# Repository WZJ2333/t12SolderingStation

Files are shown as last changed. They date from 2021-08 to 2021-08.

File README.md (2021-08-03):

# T12焊台

### 参考网址

原作者easyEda：[https://easyeda.com/wagiminator/z-solderingstation-smd-v2](https://easyeda.com/wagiminator/z-solderingstation-smd-v2)

github原项目地址：[https://github.com/wagiminator/ATmega-Soldering-Station](https://github.com/wagiminator/ATmega-Soldering-Station)

中文固件开发者：[https://github.com/createskyblue/ATmega-Soldering-Station](https://github.com/createskyblue/ATmega-Soldering-Station)

用Arduino烧录bootloader和固件教程：

[http://blog.sina.com.cn/s/blog_6f72ff900102xktj.html](http://blog.sina.com.cn/s/blog_6f72ff900102xktj.html)

[https://www.bilibili.com/video/BV1Sf4y167eS](https://www.bilibili.com/video/BV1Sf4y167eS)

[https://www.arduino.cn/forum.php？mod=viewthread&tid=100378&page=1&extra=#pid573426](https://www.arduino.cn/forum.php?mod=viewthread&tid=100378&page=1&extra=#pid573426)

[https://www.bilibili.com/video/BV1mt4y1i7GE](https://www.bilibili.com/video/BV1mt4y1i7GE)

[https://www.bilibili.com/video/BV1fy4y1y78x/](https://www.bilibili.com/video/BV1fy4y1y78x/)

b站参考视频：

[https://www.bilibili.com/video/BV1RD4y127BJ](https://www.bilibili.com/video/BV1RD4y127BJ)

[https://www.bilibili.com/video/BV1hU4y1h7u2](https://www.bilibili.com/video/BV1hU4y1h7u2)

[https://www.bilibili.com/video/BV1w7411W75V](https://www.bilibili.com/video/BV1w7411W75V)

[https://www.bilibili.com/video/BV1iE41137xJ](https://www.bilibili.com/video/BV1iE41137xJ)

### 需要额外购买的零件(BOM除外)

- 手柄套件
- 3D打印盒子
- 航空插 (GX12  4芯)
- DC 电源插座 (5.5 * 2.1 mm)
- DC电源适配器 (15V)
- 两脚开关 (KCD1 15 * 10 mm)（焊接开关的时候开关一定要处于断开状态，不然开关会被烫坏）
- 线 (截面积0.75m㎡)
- 4 个螺丝 (1.7 * 12 )
- OLED屏幕 (128x64    4个引脚,引脚要GND开头)
- 贴片编码器

### 硬件

手柄部分：

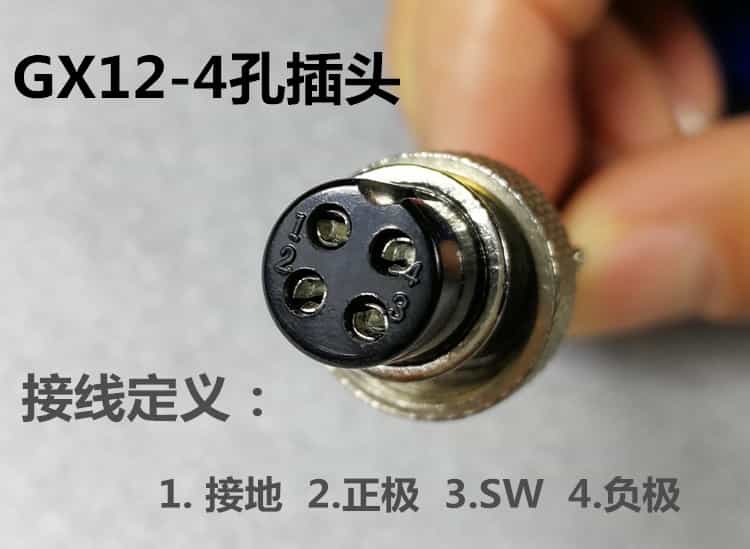
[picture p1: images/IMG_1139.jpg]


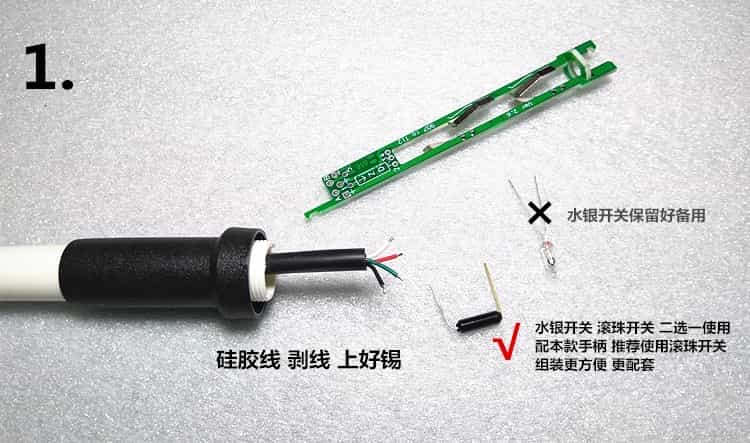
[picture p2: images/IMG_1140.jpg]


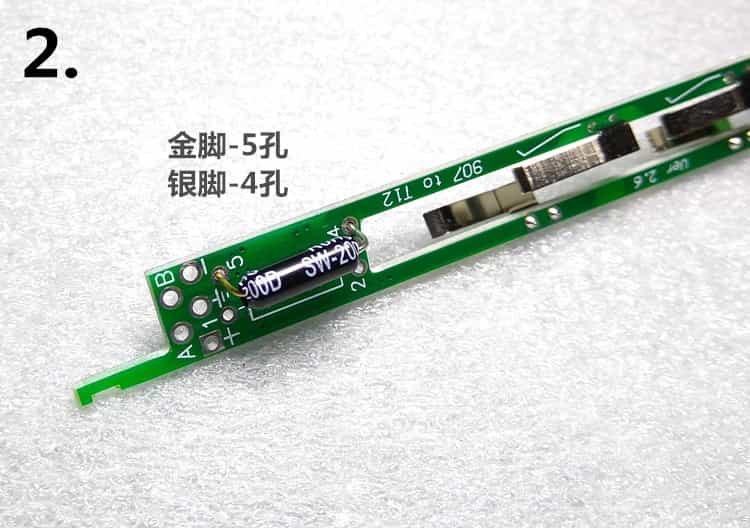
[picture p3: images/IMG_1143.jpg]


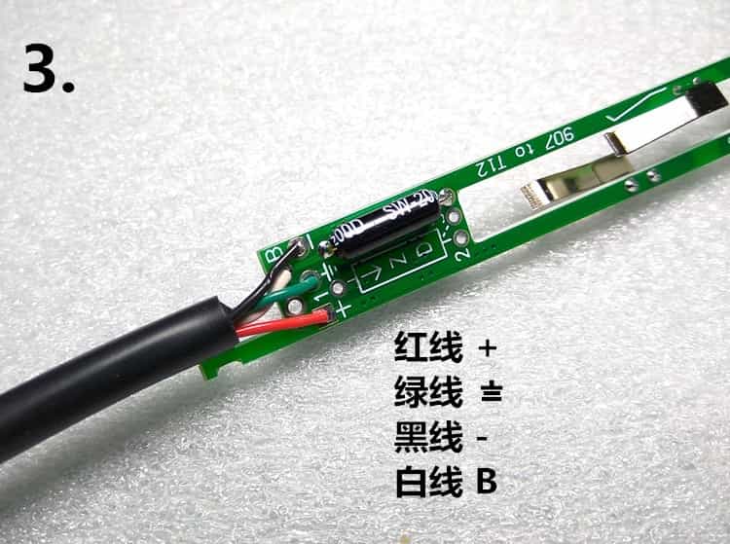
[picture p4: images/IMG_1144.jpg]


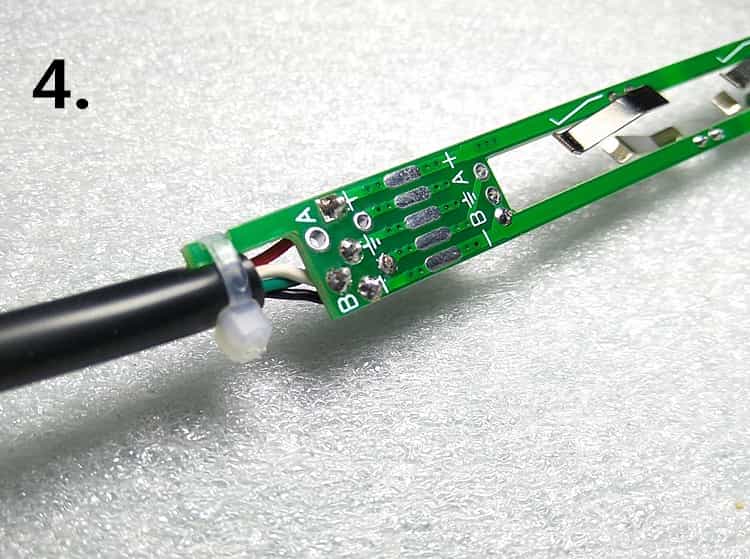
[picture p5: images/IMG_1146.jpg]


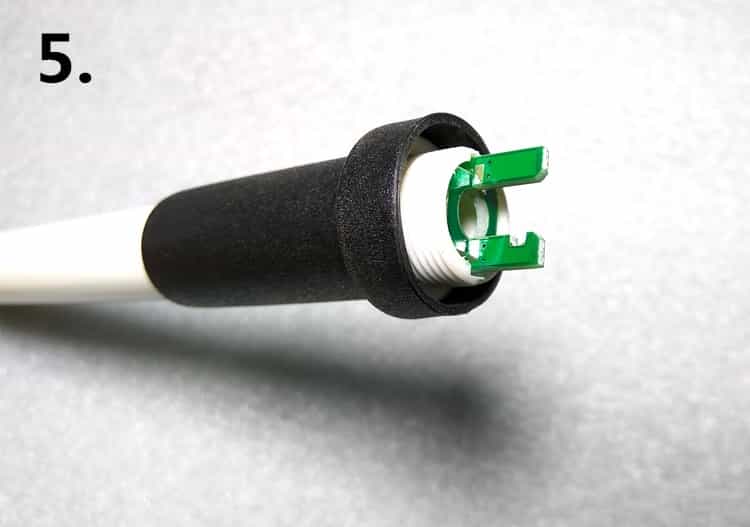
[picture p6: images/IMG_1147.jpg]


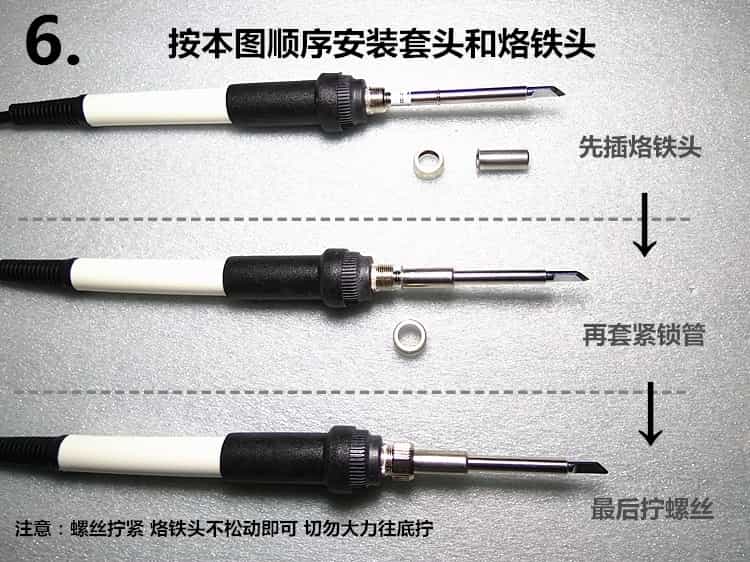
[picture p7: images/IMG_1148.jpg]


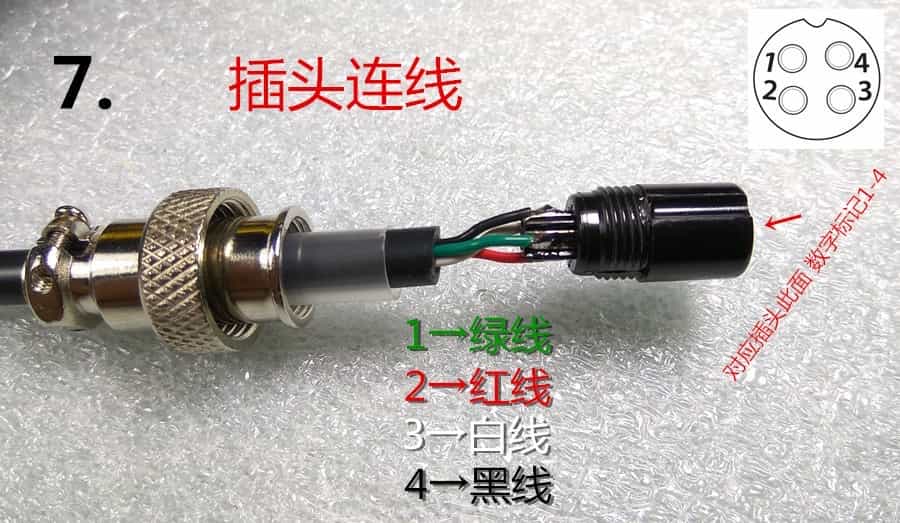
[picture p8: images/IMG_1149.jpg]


另外一种手柄的接法

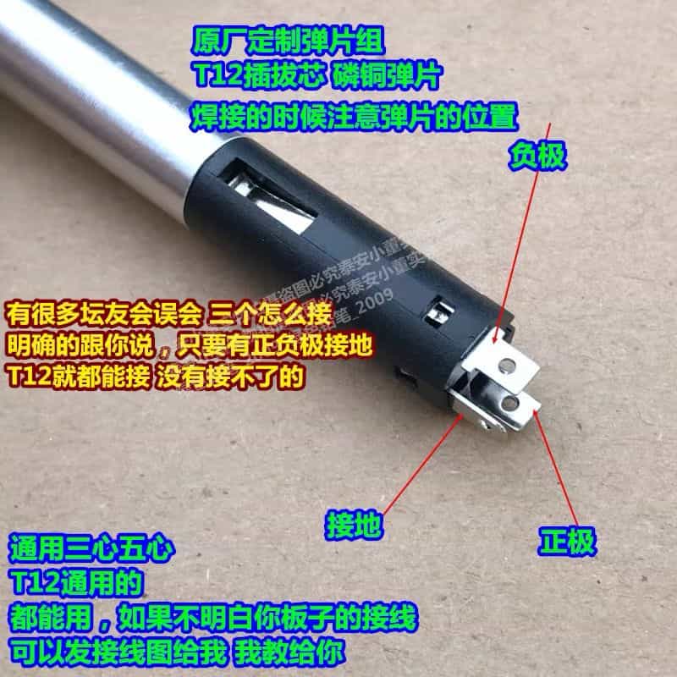
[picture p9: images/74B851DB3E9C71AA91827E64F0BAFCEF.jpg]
T12%E7%84%8A%E5%8F%B0%20b157d01f9ea6403abac089e03313d03d/74B851DB3E9C71AA91827E64F0BAFCEF.jpg


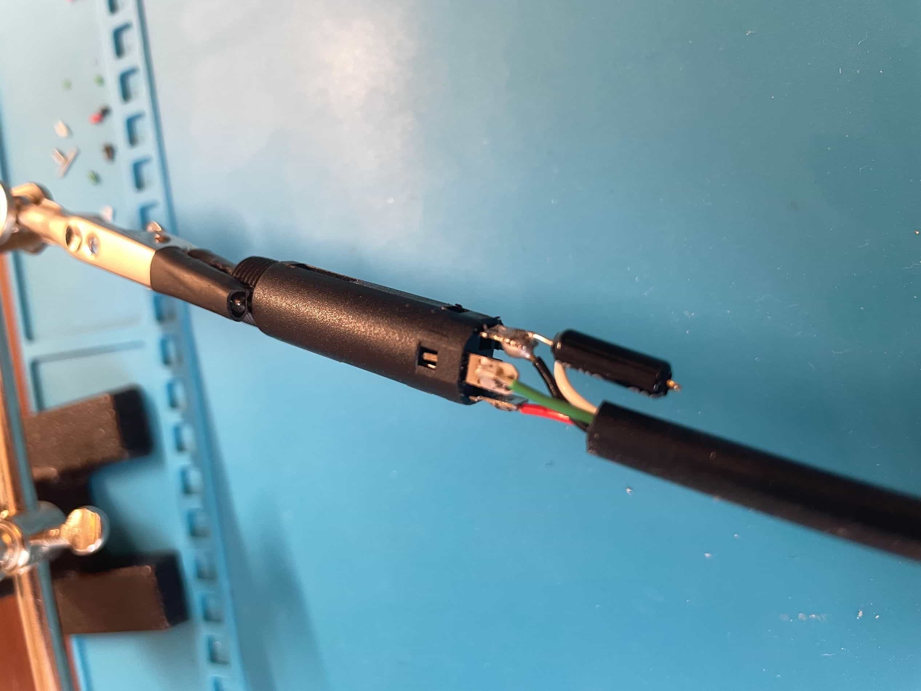
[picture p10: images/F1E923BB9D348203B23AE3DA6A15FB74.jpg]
T12%E7%84%8A%E5%8F%B0%20b157d01f9ea6403abac089e03313d03d/F1E923BB9D348203B23AE3DA6A15FB74.jpg


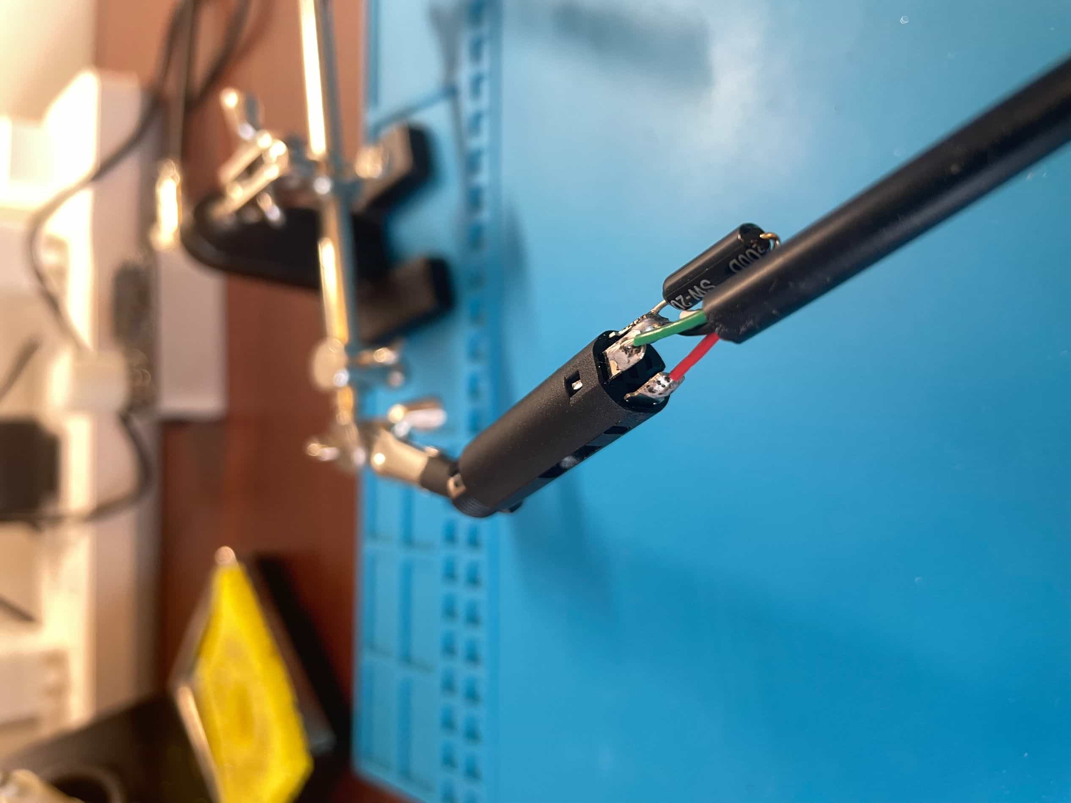
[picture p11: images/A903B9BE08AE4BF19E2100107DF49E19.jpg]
T12%E7%84%8A%E5%8F%B0%20b157d01f9ea6403abac089e03313d03d/A903B9BE08AE4BF19E2100107DF49E19.jpg


白色的线接金色引脚

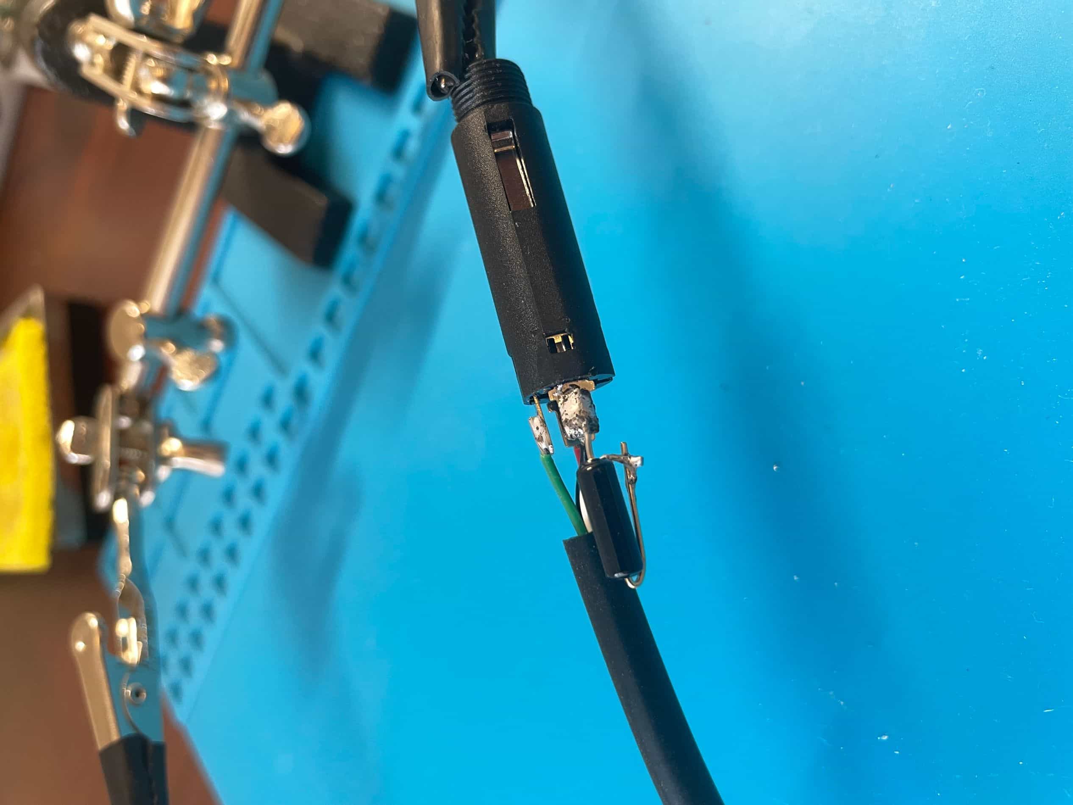
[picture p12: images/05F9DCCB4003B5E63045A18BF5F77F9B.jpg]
T12%E7%84%8A%E5%8F%B0%20b157d01f9ea6403abac089e03313d03d/05F9DCCB4003B5E63045A18BF5F77F9B.jpg


焊台部分：

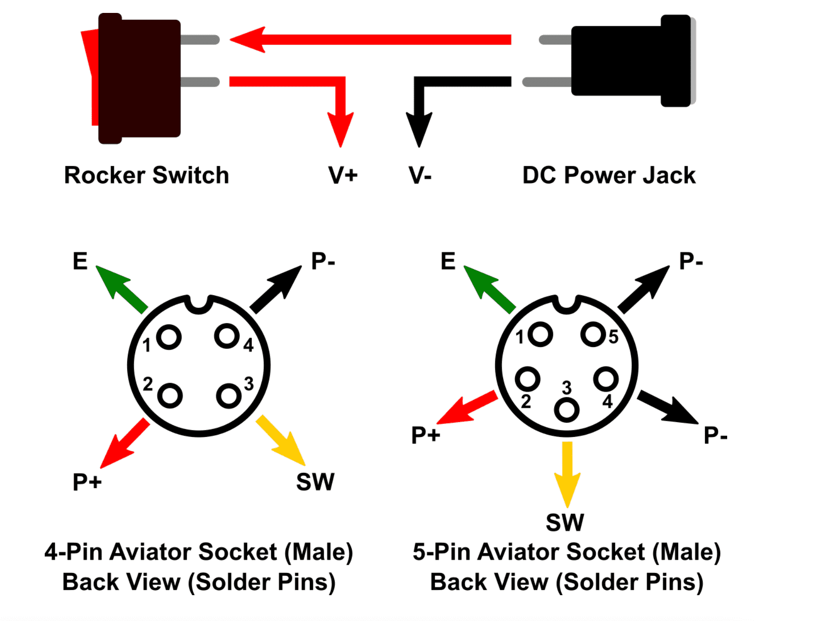
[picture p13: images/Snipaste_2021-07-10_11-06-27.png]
T12%E7%84%8A%E5%8F%B0%20b157d01f9ea6403abac089e03313d03d/Snipaste_2021-07-10_11-06-27.png


### 固件

1、Arduino的IDE安装u8glib库和PID_v1等其他需要的库(可以直接在IDE中下载导入，也可以直接把库文件拖进ArduinoIDE的libraries文件夹中)

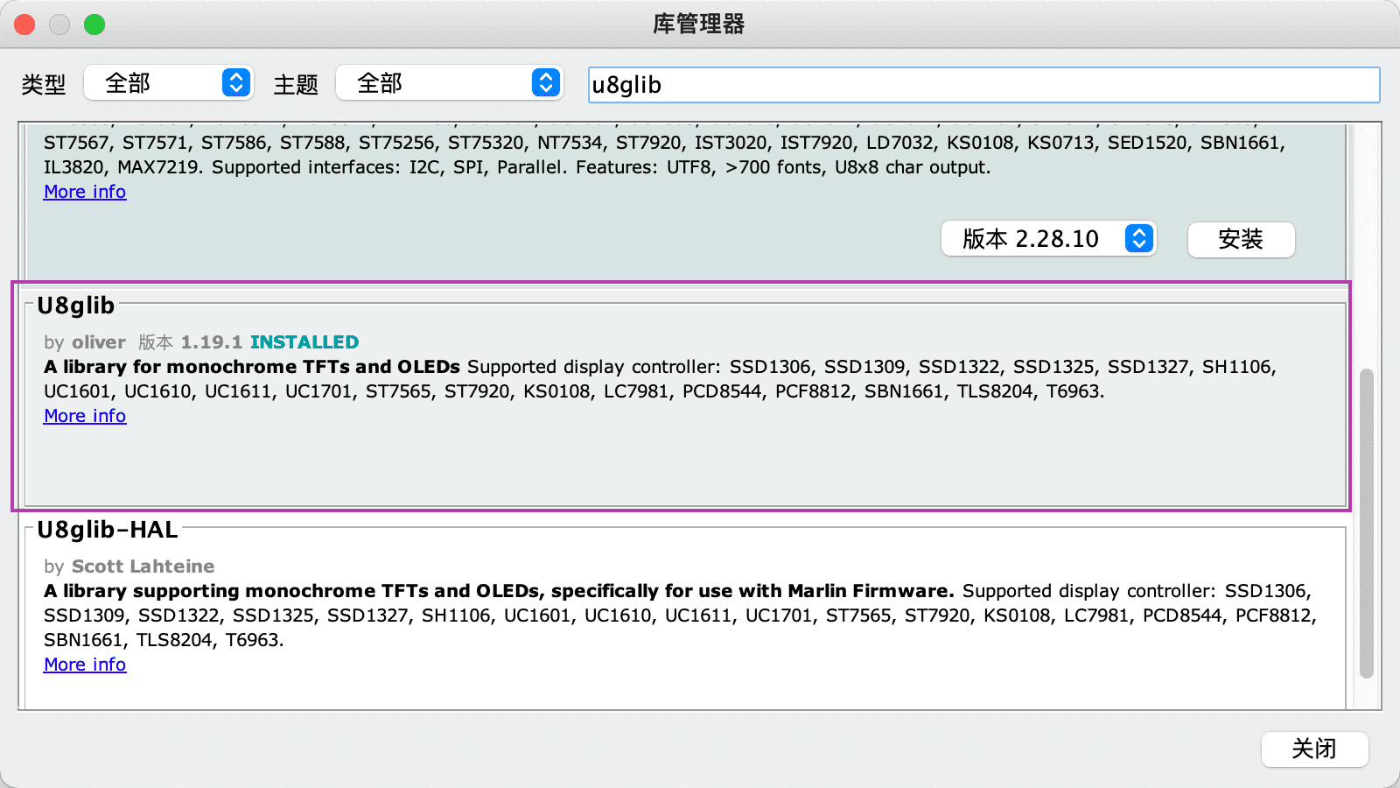
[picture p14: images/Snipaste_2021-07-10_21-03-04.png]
T12%E7%84%8A%E5%8F%B0%20b157d01f9ea6403abac089e03313d03d/Snipaste_2021-07-10_21-03-04.png


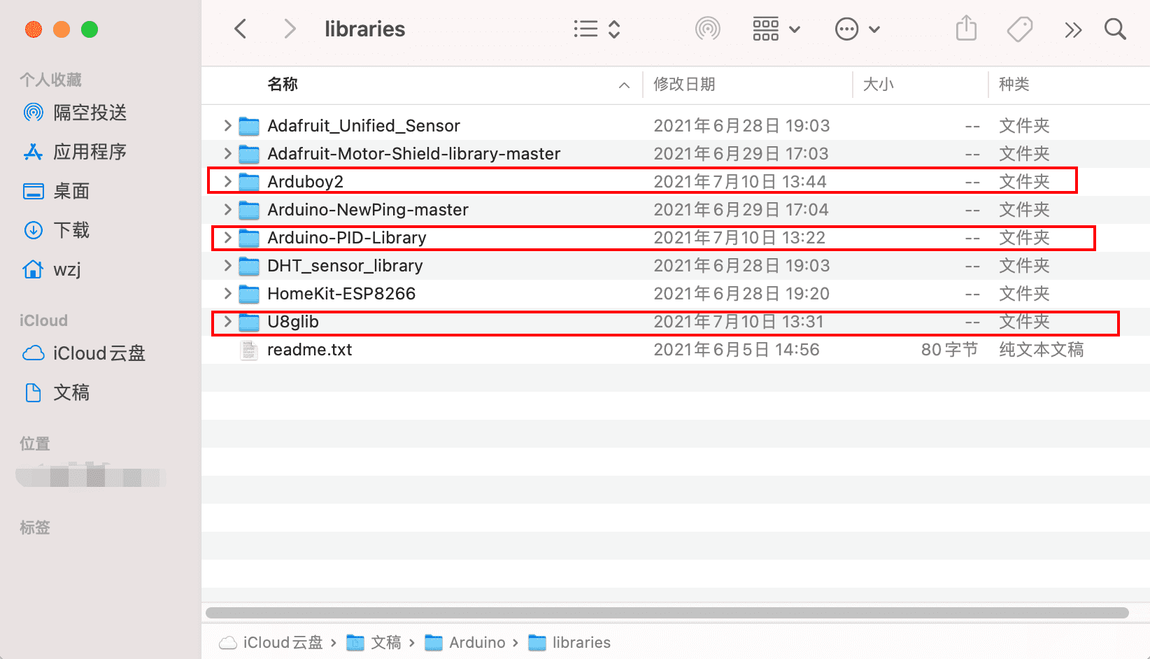
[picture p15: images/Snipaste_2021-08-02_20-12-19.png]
T12%E7%84%8A%E5%8F%B0%20b157d01f9ea6403abac089e03313d03d/Snipaste_2021-08-02_20-12-19.png


2、连接(ArduinoUNO连上 电脑 和 T12控制板的ICSP)

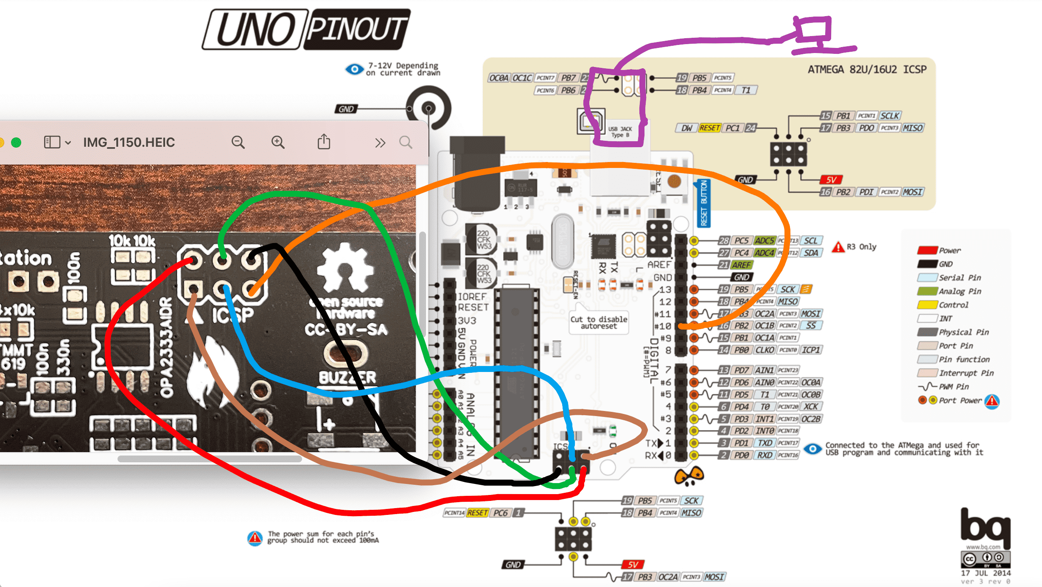
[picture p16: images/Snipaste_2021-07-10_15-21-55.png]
T12%E7%84%8A%E5%8F%B0%20b157d01f9ea6403abac089e03313d03d/Snipaste_2021-07-10_15-21-55.png


3、新建ArduinoISP项目

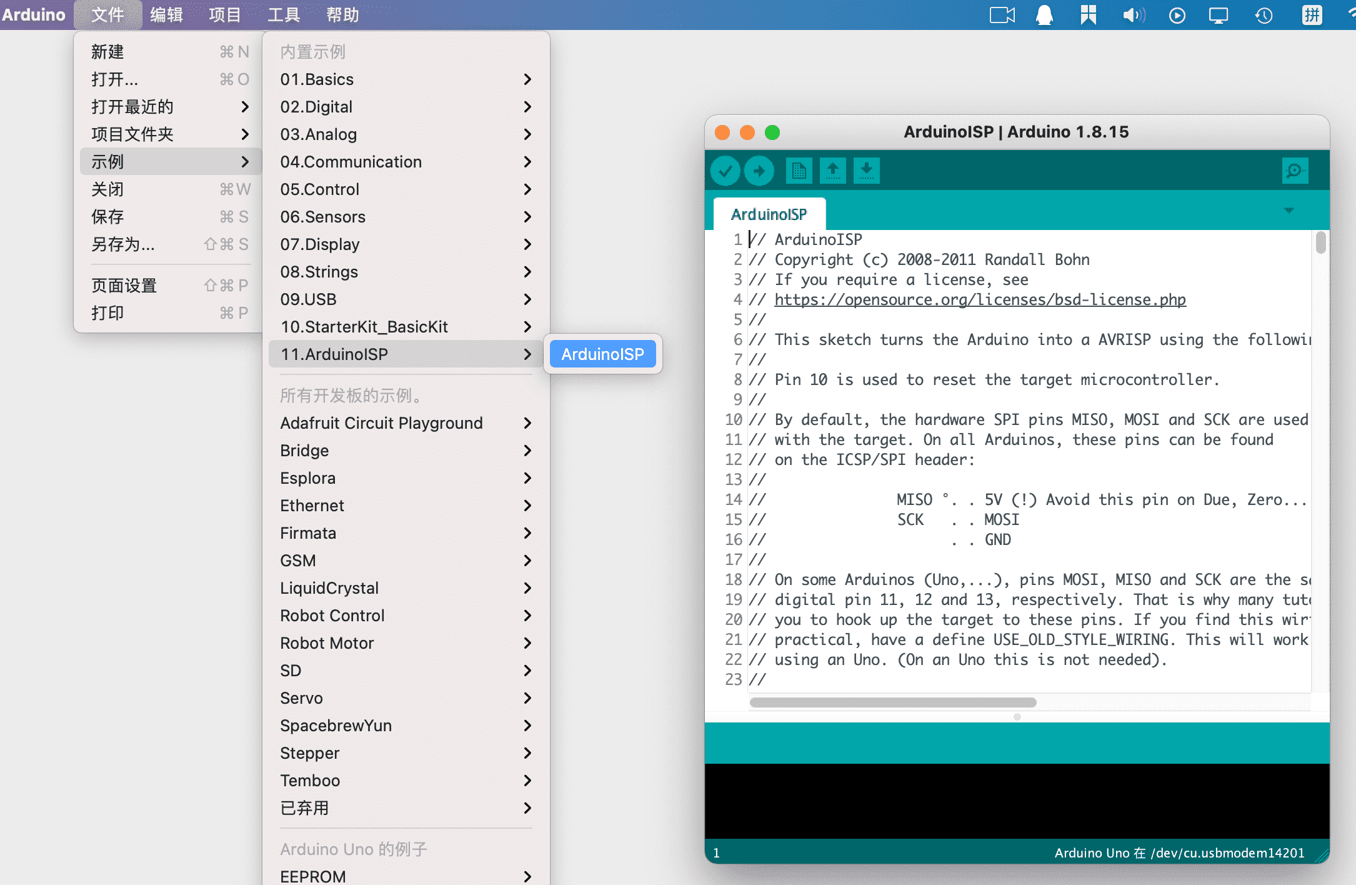
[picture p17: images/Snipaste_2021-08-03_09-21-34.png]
T12%E7%84%8A%E5%8F%B0%20b157d01f9ea6403abac089e03313d03d/Snipaste_2021-08-03_09-21-34.png


先编译然后上传

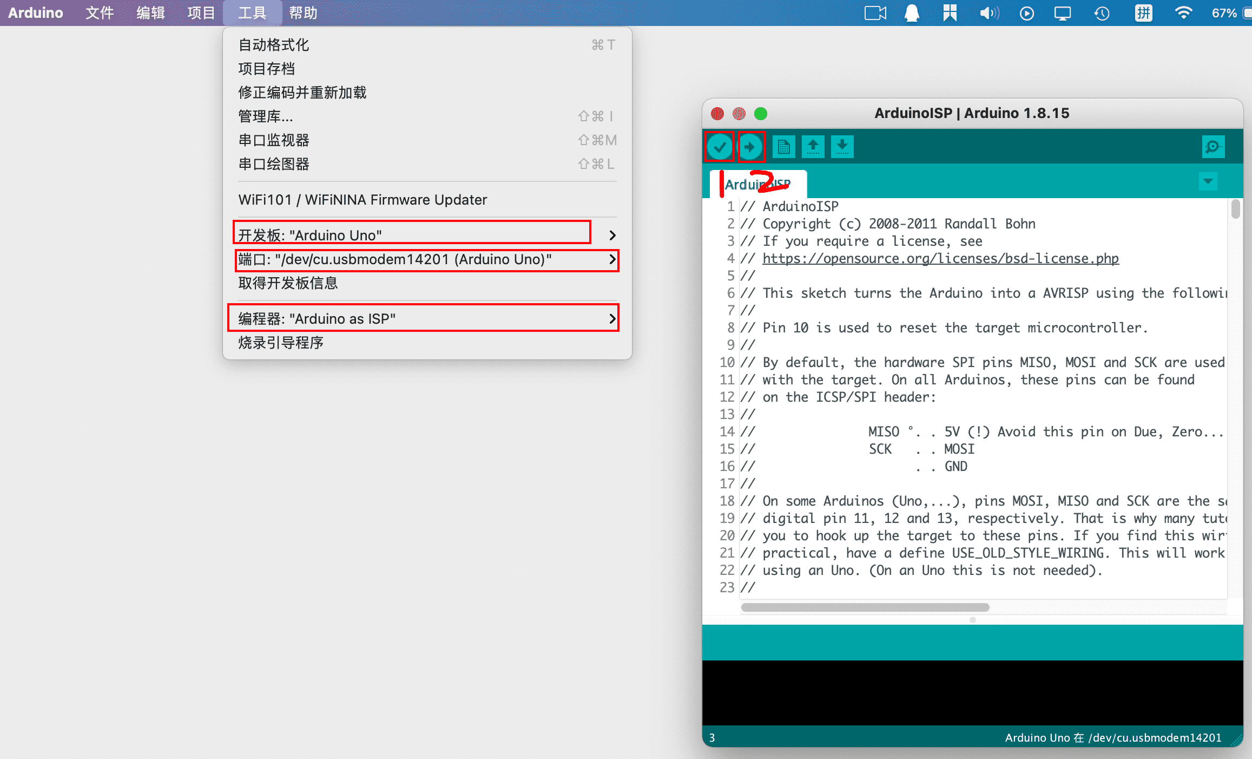
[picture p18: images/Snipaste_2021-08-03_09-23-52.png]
T12%E7%84%8A%E5%8F%B0%20b157d01f9ea6403abac089e03313d03d/Snipaste_2021-08-03_09-23-52.png


4、点击烧录引导程序(bootloader)，到T12的主控(ATMEGA328P)中，成功之后关掉这个项目

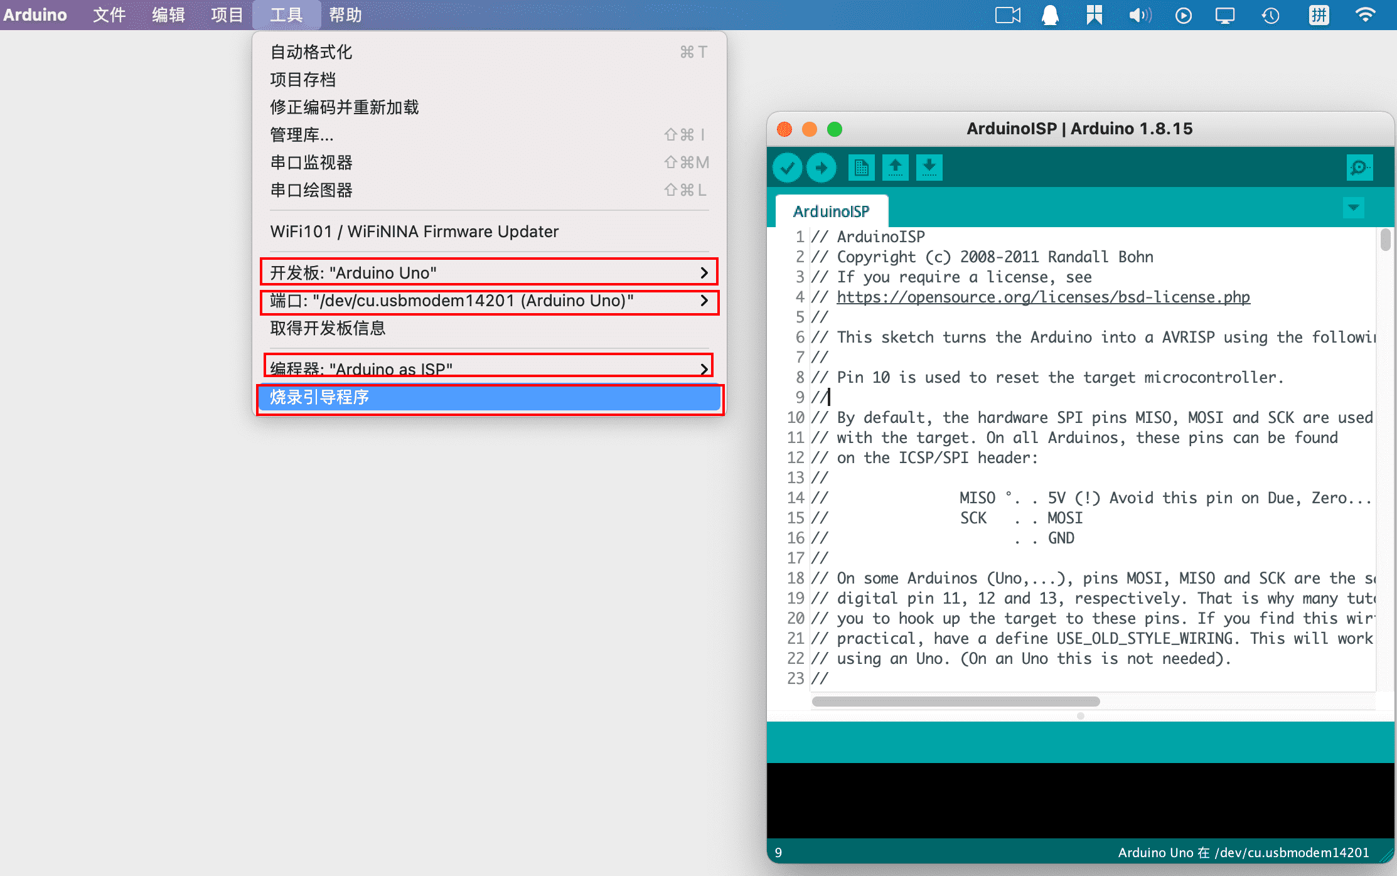
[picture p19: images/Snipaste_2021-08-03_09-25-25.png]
T12%E7%84%8A%E5%8F%B0%20b157d01f9ea6403abac089e03313d03d/Snipaste_2021-08-03_09-25-25.png


5、烧录固件

打开T12的源码，先点击编译，然后点击使用编程器上传，成功之后T12焊台的屏幕会被点亮

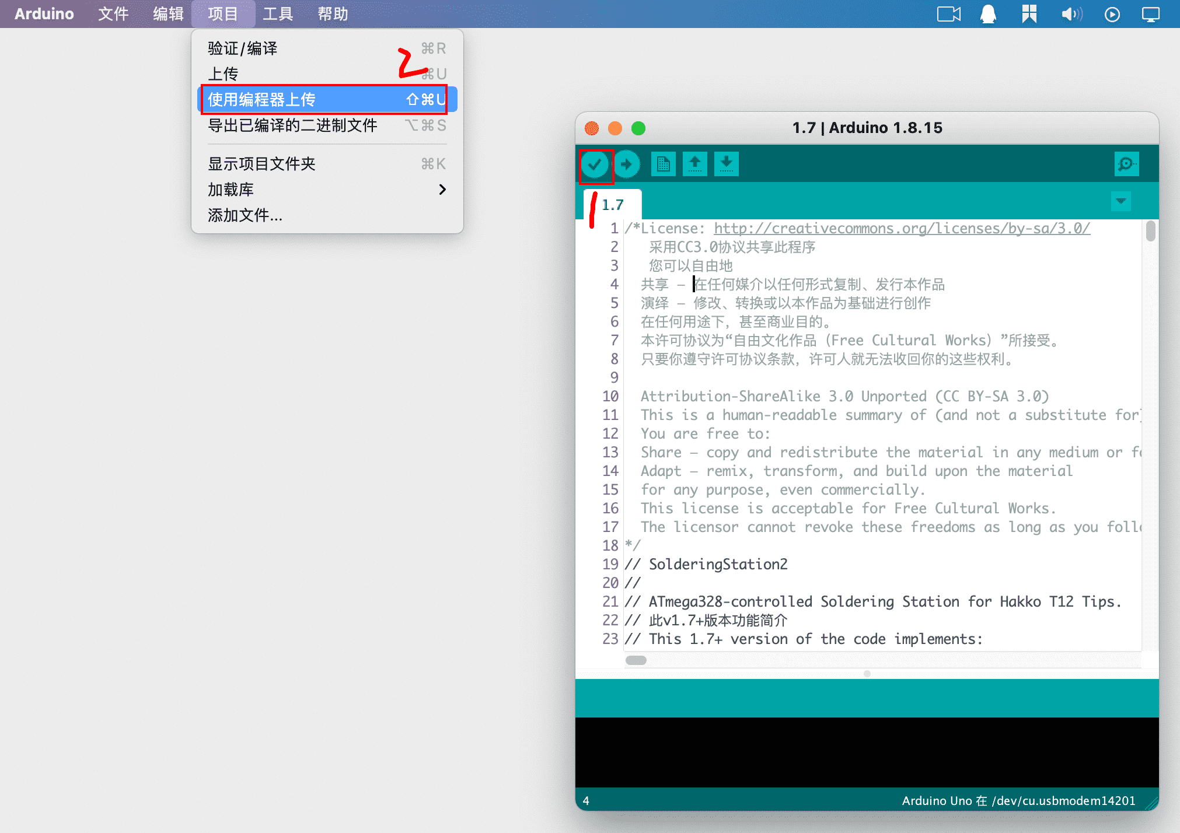
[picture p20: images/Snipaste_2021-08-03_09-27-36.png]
T12%E7%84%8A%E5%8F%B0%20b157d01f9ea6403abac089e03313d03d/Snipaste_2021-08-03_09-27-36.png


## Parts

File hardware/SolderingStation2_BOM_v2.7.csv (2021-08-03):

ID | Name | Designator | Footprint | Quantity | Manufacturer Part | Manufacturer | Supplier | Supplier Part | LCSC Assembly
1 | 1N4148W | D2 | DIODE-SOD-123 | 1 | 1N4148W-E3-08 | Vishay Intertech | LCSC | C241939
2 | LMV358IDR | U3 | SOP-8_150MIL | 1 | LMV358IDR | TI | LCSC | C63813 | Yes
3 | 16MHZ | X1 | HC-49S | 1 | X49SD16MSD2SI | Yangxing Tech | LCSC | C188201
4 | MLT-5030 | BUZZER1 | MLT-5030 | 1 | MLT-5030 | HNDZ | LCSC | C95297
6 | BZT52-B18 | D4 | ZENER-SOD-123 | 1 | MM1Z18 | Jingdao | LCSC | C116111 | Yes
7 | MM1Z5V1 | D3 | ZENER-SOD-123 | 1 | MM1Z5V1 | SEMTECH | LCSC | C81601 | Yes
8 | 47k | R12 | 603 | 1 | 0603WAF4702T5E | UniOhm | LCSC | C25819
9 | 1k5 | R2 | 603 | 1 | 0603WAF1501T5E | UniOhm | LCSC | C22843
10 | 10k | R11,R13,R3,R4,R6,R7,R14,R10,R1 | 603 | 9 | 0603WAF1002T5E | UniOhm | LCSC | C25804
11 | 1k | R9 | 603 | 1 | 0603WAF1001T5E | UniOhm | LCSC | C21190
12 | 200k | R8 | 603 | 1 | 0603WAF2003T5E | UniOhm | LCSC | C25811
13 | IRLR7843TRPBF | Q2 | TO-252-2 | 1 | IRLR7843TRPBF | IR | LCSC | C21988 | Yes
16 | 3x6x2.5 | RESET | KEY-3.0*6.0 | 1 | 3x6x2.5Red head high temperature | ReliaPro | LCSC | C46491
18 | 100n | C10,C1,C9,C3,C2 | 603 | 5 | CC0603KRX7R9BB104 | YAGEO | LCSC | C14663
19 | 1u | C13 | 603 | 1 | CL10A105KB8NNNC | SAMSUNG | LCSC | C15849
20 | 330n | C11 | 603 | 1 | C1608X7R1H334KT000E | TDK | LCSC | C76621
21 | 22p | C5,C6 | 603 | 2 | CL10C220JB8NNNC | SAMSUNG | LCSC | C1653
22 | 2n2 | C8 | 603 | 1 | 0603B222K500NT | FH | LCSC | C1604
23 | 1k | R5 | 1206 | 1 | 1206W4F1001T5E | UniOhm | LCSC | C4410
24 | 47u | C4 | 1206 | 1 | 1206F476M100NT | FH | LCSC | C30349
25 | 22u | C12 | 1206 | 1 | C3216X5R1V226MTJ00E | TDK | LCSC | C342620
26 | 10u | C7 | 1206 | 1 | GMK316BJ106KL-T | Taiyo Yuden | LCSC | C92797
27 | 78M05 | U2 | TO-252-2 | 1 | ME78M05K3G | MICRONE | LCSC | C83969 | Yes
28 | PWR | LED1 | LED0603 | 1 | 19-217/BHC-ZL1M2RY/3T | EVERLIGHT | LCSC | C72041
29 | FMMT619 | Q1 | SOT-23-3_L2.9-W1.6-P1.90-LS2.8-BR | 1 | FMMT619 | CJ | LCSC | C53071 | Yes
30 | SS54 | D1 | DIODE-SMA(DO-214AC) | 1 | SS54 | Jingdao | LCSC | C123946 | Yes
31 | ATMEGA328P-AU | U1 | TQFP-32_7X7X08P | 1 | ATMEGA328P-AU | MICROCHIP | LCSC | C14877 | Yes

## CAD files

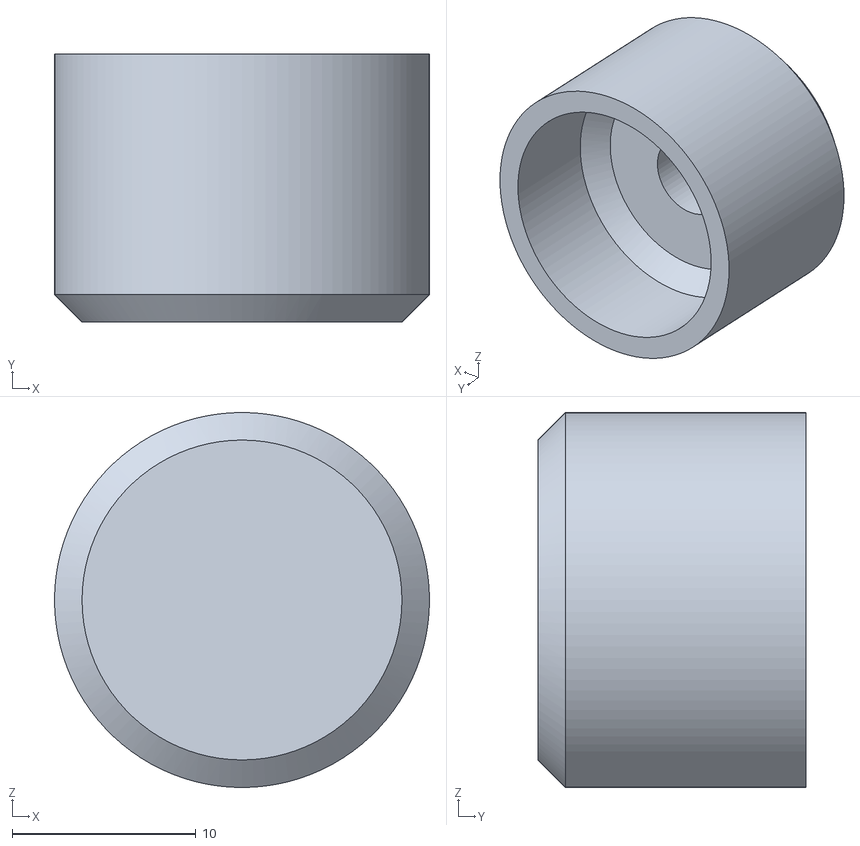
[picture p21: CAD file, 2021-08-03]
3dprint/Soldering2.stl
20.4 x 14.6 x 20.4

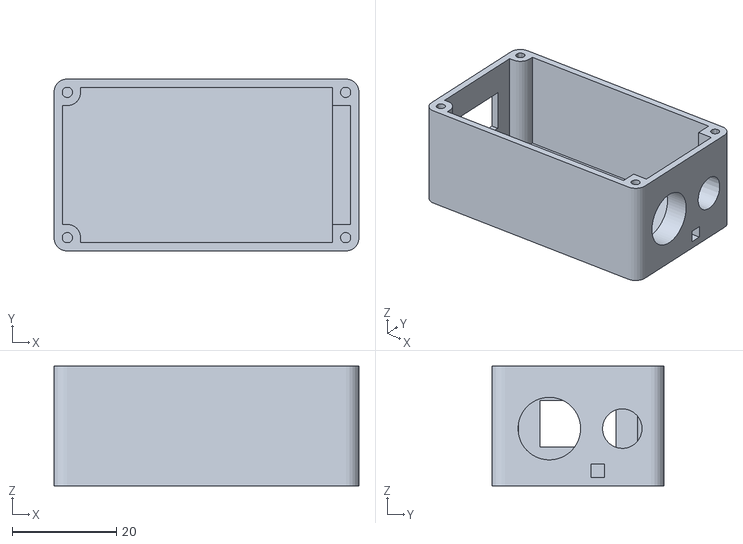
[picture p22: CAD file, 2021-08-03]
3dprint/Soldering1.stl
58.5 x 33.0 x 23.0

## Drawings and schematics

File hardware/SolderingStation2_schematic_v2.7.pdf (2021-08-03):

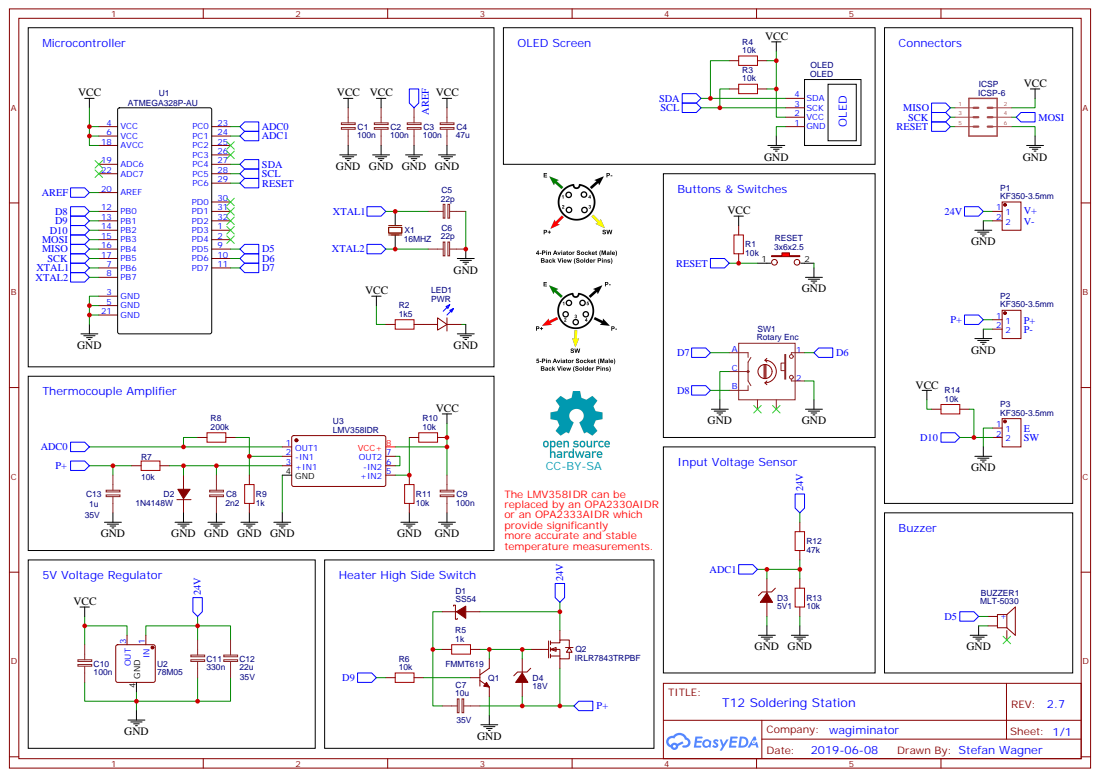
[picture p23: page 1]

GND GND

The LMV358IDR can be
replaced by an OPA2330AIDR
or an OPA2333AIDR which
provide significantly
more accurate and stable
temperature measurements.

Heater High Side Switch

Drawn By: Stefan Wagner

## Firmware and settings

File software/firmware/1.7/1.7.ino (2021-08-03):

/*License: http://creativecommons.org/licenses/by-sa/3.0/
   采用CC3.0协议共享此程序
   您可以自由地
  共享 — 在任何媒介以任何形式复制、发行本作品
  演绎 — 修改、转换或以本作品为基础进行创作
  在任何用途下，甚至商业目的。
  本许可协议为“自由文化作品（Free Cultural Works）”所接受。
  只要你遵守许可协议条款，许可人就无法收回你的这些权利。

  Attribution-ShareAlike 3.0 Unported (CC BY-SA 3.0)
  This is a human-readable summary of (and not a substitute for) the license. Disclaimer.
  You are free to:
  Share — copy and redistribute the material in any medium or format
  Adapt — remix, transform, and build upon the material
  for any purpose, even commercially.
  This license is acceptable for Free Cultural Works.
  The licensor cannot revoke these freedoms as long as you follow the license terms.
*/
// SolderingStation2
//
// ATmega328-controlled Soldering Station for Hakko T12 Tips.
// 此v1.7+版本功能简介
// This 1.7+ version of the code implements:
// - 烙铁头温度实时监测
// - Temperature measurement of the tip
// - PID温度控制
// - Direct or PID control of the heater
// - 可以通过编码器进行控制温度
// - Temperature control via rotary encoder
// - 短按编码器进入短时升温模式
// - Boost mode by short pressing rotary encoder switch
// - 长按编码器进入主菜单
// - Setup menu by long pressing rotary encoder switch
// - 手柄震动检测（需要手柄含有震动传感器）
// - Handle movement detection (by checking ball switch)
// - 手柄连接检测（通过判断烙铁头温度是否能够被读取来实现）
// - Iron unconnected detection (by idenfying invalid temperature readings)
// - 定时器设定 - 随眠，关机时间
// - Time driven sleep/power off mode if iron is unused (movement detection)
// - 可以测量主控芯片电压以及温度
// - Measurement of input voltage, Vcc and ATmega's internal temperature
// - 在OLED上实现信息显示
// - Information display on OLED
// - 支持无源蜂鸣器
// - Buzzer
// - 允许设置不同烙铁头的温度校准值
// - Calibrating and managing different soldering tips
// - 设置被保存在EEPROM，掉电不丢失
// - Storing user settings into the EEPROM
// - 允许热插拔烙铁头，并弹出烙铁头配置选择菜单
// - Tip change detection
// - 芯片过热以及低电压报警
// - Chip overheating and low voltage alarm
// - 更好的实时温度条以及实时功率条
// - Better real-time temperature bar and real-time power bar
// - 拥有过渡动画
// - Have transition animation
// - 内置屏幕保护程序
// - Built in screen saver
// - 屏幕翻转设置
// - Screen flip settings
// - 内置英文、中文、日文语言包
// - Built in English, Chinese and Japanese language pack
// - 开机密码设置
// - System Password

// Power supply should be in the range of 16V/2A to 24V/3A and well
// stabilized.
//
// For calibration you need a soldering iron tips thermometer. For best results
// wait at least three minutes after switching on the soldering station before
// you start the calibration process.
//
// Controller:  ATmega328p
// Core:        Barebones ATmega (https://github.com/carlosefr/atmega)
// Clockspeed:  16 MHz external
//
// 2019/2020 by Stefan Wagner with great support from John Glavinos
// 2020-8 UI upgrade by LHW-createskyblue 、lihaoyun6
// Project Page: https://easyeda.com/wagiminator

//关于界面-项目页面二维码 ->为了加入欠压报警只能阉割掉关于页面的二维码
//const unsigned char QRCode[] PROGMEM = { 0x00, 0x00, 0x3e, 0x0e, 0x7c, 0x0c, 0x00, 0x00, 0x00, 0x00, 0x3e, 0x0e, 0x7c, 0x0c, 0x00, 0x00, 0x00, 0x00, 0x3e, 0x0e, 0x7c, 0x0c, 0x00, 0x00, 0x1f, 0xfe, 0x3f, 0xc1, 0x8c, 0x0c, 0x7f, 0xf8, 0x1f, 0xfe, 0x3f, 0xc1, 0x8c, 0x0c, 0x7f, 0xf8, 0x18, 0x06, 0x30, 0x01, 0xf3, 0x8c, 0x60, 0x18, 0x18, 0x06, 0x30, 0x01, 0xf3, 0x8c, 0x60, 0x18, 0x18, 0x06, 0x30, 0x01, 0xf3, 0x8c, 0x60, 0x18, 0x18, 0x06, 0x3e, 0x0f, 0xf0, 0x0c, 0x60, 0x18, 0x18, 0x06, 0x3e, 0x0f, 0xf0, 0x0c, 0x60, 0x18, 0x18, 0x06, 0x3f, 0xc1, 0xf0, 0x0c, 0x60, 0x18, 0x18, 0x06, 0x3f, 0xc1, 0xf0, 0x0c, 0x60, 0x18, 0x18, 0x06, 0x3f, 0xc1, 0xf0, 0x0c, 0x60, 0x18, 0x1f, 0xfe, 0x3e, 0x30, 0x70, 0x0c, 0x7f, 0xf8, 0x1f, 0xfe, 0x3e, 0x30, 0x70, 0x0c, 0x7f, 0xf8, 0x00, 0x00, 0x31, 0xce, 0x73, 0x8c, 0x00, 0x00, 0x00, 0x00, 0x31, 0xce, 0x73, 0x8c, 0x00, 0x00, 0x00, 0x00, 0x31, 0xce, 0x73, 0x8c, 0x00, 0x00, 0xff, 0xff, 0xf0, 0x01, 0x83, 0x8f, 0xff, 0xff, 0xff, 0xff, 0xf0, 0x01, 0x83, 0x8f, 0xff, 0xff, 0x00, 0xc0, 0x01, 0xc1, 0x8c, 0x00, 0x7f, 0x1f, 0x00, 0xc0, 0x01, 0xc1, 0x8c, 0x00, 0x7f, 0x1f, 0x00, 0xc0, 0x01, 0xc1, 0x8c, 0x00, 0x7f, 0x1f, 0x07, 0xc7, 0xcf, 0xce, 0x7f, 0x8c, 0x1f, 0xf8, 0x07, 0xc7, 0xcf, 0xce, 0x7f, 0x8c, 0x1f, 0xf8, 0x07, 0xc7, 0xcf, 0xce, 0x7f, 0x8c, 0x1f, 0xf8, 0xf8, 0x00, 0x3e, 0x3e, 0x03, 0xf0, 0x7f, 0x00, 0xf8, 0x00, 0x3e, 0x3e, 0x03, 0xf0, 0x7f, 0x00, 0xe0, 0xc7, 0xcf, 0xfe, 0x03, 0x80, 0x1f, 0xe7, 0xe0, 0xc7, 0xcf, 0xfe, 0x03, 0x80, 0x1f, 0xe7, 0xe0, 0xc7, 0xcf, 0xfe, 0x03, 0x80, 0x1f, 0xe7, 0x18, 0xc0, 0x31, 0xfe, 0x0c, 0x0c, 0x1c, 0xe0, 0x18, 0xc0, 0x31, 0xfe, 0x0c, 0x0c, 0x1c, 0xe0, 0xe7, 0x39, 0xf1, 0xf0, 0x03, 0xfc, 0x7c, 0xf8, 0xe7, 0x39, 0xf1, 0xf0, 0x03, 0xfc, 0x7c, 0xf8, 0xe7, 0x39, 0xf1, 0xf0, 0x03, 0xfc, 0x7c, 0xf8, 0x1f, 0x00, 0x31, 0xcf, 0xf3, 0x8c, 0x03, 0x00, 0x1f, 0x00, 0x31, 0xcf, 0xf3, 0x8c, 0x03, 0x00, 0xe0, 0x3f, 0xff, 0xc1, 0x83, 0x8f, 0x9c, 0xe7, 0xe0, 0x3f, 0xff, 0xc1, 0x83, 0x8f, 0x9c, 0xe7, 0xe0, 0x3f, 0xff, 0xc1, 0x83, 0x8f, 0x9c, 0xe7, 0x18, 0x00, 0x30, 0x0e, 0x00, 0x00, 0x00, 0xff, 0x18, 0x00, 0x30, 0x0e, 0x00, 0x00, 0x00, 0xff, 0x18, 0x00, 0x30, 0x0e, 0x00, 0x00, 0x00, 0xff, 0xff, 0xff, 0xf0, 0x3e, 0x7c, 0x0f, 0xe0, 0x00, 0xff, 0xff, 0xf0, 0x3e, 0x7c, 0x0f, 0xe0, 0x00, 0x00, 0x00, 0x31, 0xce, 0x0c, 0x0c, 0x63, 0xe0, 0x00, 0x00, 0x31, 0xce, 0x0c, 0x0c, 0x63, 0xe0, 0x00, 0x00, 0x31, 0xce, 0x0c, 0x0c, 0x63, 0xe0, 0x1f, 0xfe, 0x30, 0x01, 0x83, 0x8f, 0xe0, 0xff, 0x1f, 0xfe, 0x30, 0x01, 0x83, 0x8f, 0xe0, 0xff, 0x18, 0x06, 0x31, 0xf1, 0x8f, 0x80, 0x03, 0xe7, 0x18, 0x06, 0x31, 0xf1, 0x8f, 0x80, 0x03, 0xe7, 0x18, 0x06, 0x31, 0xf1, 0x8f, 0x80, 0x03, 0xe7, 0x18, 0x06, 0x3f, 0xff, 0x83, 0x83, 0xe3, 0x1f, 0x18, 0x06, 0x3f, 0xff, 0x83, 0x83, 0xe3, 0x1f, 0x18, 0x06, 0x31, 0xfe, 0x73, 0x8f, 0x80, 0xf8, 0x18, 0x06, 0x31, 0xfe, 0x73, 0x8f, 0x80, 0xf8, 0x18, 0x06, 0x31, 0xfe, 0x73, 0x8f, 0x80, 0xf8, 0x1f, 0xfe, 0x31, 0xfe, 0x00, 0x0c, 0x60, 0xe7, 0x1f, 0xfe, 0x31, 0xfe, 0x00, 0x0c, 0x60, 0xe7, 0x00, 0x00, 0x31, 0xfe, 0x0c, 0x0f, 0x9f, 0xe0, 0x00, 0x00, 0x31, 0xfe, 0x0c, 0x0f, 0x9f, 0xe0, 0x00, 0x00, 0x31, 0xfe, 0x0c, 0x0f, 0x9f, 0xe0 };
const unsigned char QRCode[] PROGMEM = { 0xff, 0xff, 0xff, 0xff, 0xff, 0xff, 0x80, 0x03, 0x86, 0x70, 0x80, 0x03, 0x80, 0x03, 0x86, 0x70, 0x80, 0x03, 0x9f, 0xf3, 0xe1, 0x30, 0x9f, 0xf3, 0x9f, 0xf3, 0xe1, 0x30, 0x9f, 0xf3, 0x98, 0x33, 0x01, 0xcc, 0x98, 0x33, 0x98, 0x33, 0x01, 0xcc, 0x98, 0x33, 0x98, 0x33, 0x87, 0xc0, 0x98, 0x33, 0x98, 0x33, 0xe1, 0xc0, 0x98, 0x33, 0x98, 0x33, 0xe1, 0xc0, 0x98, 0x33, 0x9f, 0xf3, 0x98, 0xc0, 0x9f, 0xf3, 0x9f, 0xf3, 0x98, 0xc0, 0x9f, 0xf3, 0x80, 0x03, 0x66, 0xcc, 0x80, 0x03, 0x80, 0x03, 0x66, 0xcc, 0x80, 0x03, 0xff, 0xff, 0x01, 0x0c, 0xff, 0xff, 0xff, 0xff, 0x01, 0x00, 0x1f, 0xff, 0x81, 0x00, 0x61, 0x30, 0x1f, 0x3f, 0x87, 0x3c, 0xe6, 0xfc, 0x87, 0x33, 0x87, 0x3c, 0xe6, 0xfc, 0x87, 0xf3, 0xf8, 0x03, 0x9e, 0x0f, 0x1f, 0x03, 0xf8, 0x03, 0x9e, 0x0f, 0x1f, 0x03, 0xe1, 0x3c, 0xfe, 0x0c, 0x07, 0xcf, 0xe1, 0x3c, 0xfe, 0x0c, 0x07, 0xcf, 0x99, 0x03, 0x3e, 0x30, 0x86, 0xc3, 0xe6, 0xcf, 0x38, 0x0f, 0x9e, 0xf3, 0xe6, 0xcf, 0x38, 0x0f, 0x9e, 0xf3, 0x9e, 0x03, 0x27, 0xcc, 0x81, 0x03, 0x9e, 0x03, 0x27, 0xcc, 0x81, 0x03, 0xe0, 0xff, 0xe1, 0x0c, 0xe6, 0xcf, 0xe0, 0xff, 0xe1, 0x0c, 0xe6, 0xcf, 0x98, 0x03, 0x06, 0x00, 0x00, 0xff, 0x98, 0x03, 0x06, 0x00, 0x00, 0xff, 0xff, 0xff, 0x1e, 0xf0, 0xf8, 0x03, 0x80, 0x03, 0x66, 0x30, 0x99, 0xc3, 0x80, 0x03, 0x66, 0x30, 0x99, 0xc3, 0x9f, 0xf3, 0x01, 0x0c, 0xf8, 0xff, 0x9f, 0xf3, 0x01, 0x0c, 0xf8, 0xff, 0x98, 0x33, 0x39, 0x3c, 0x01, 0xcf, 0x98, 0x33, 0x39, 0x3c, 0x01, 0xcf, 0x98, 0x33, 0xff, 0x0c, 0x79, 0x3f, 0x98, 0x33, 0x3e, 0xcc, 0xe0, 0xf3, 0x98, 0x33, 0x3e, 0xcc, 0xe0, 0xf3, 0x9f, 0xf3, 0x3e, 0x00, 0x98, 0xcf, 0x9f, 0xf3, 0x3e, 0x00, 0x98, 0xcf, 0x80, 0x03, 0x3e, 0x30, 0xe7, 0xc3, 0x80, 0x03, 0x3e, 0x30, 0xe7, 0xc3, 0xff, 0xff, 0xff, 0xff, 0xff, 0xff, 0xff, 0xff, 0xff, 0xff, 0xff, 0xff };
//ICO
//width:16,height:16
const unsigned char Tag[] PROGMEM = { 0x00, 0x00, 0x3b, 0xec, 0x7b, 0xee, 0x63, 0xe6, 0x63, 0xe6, 0x63, 0xe6, 0x63, 0xe6, 0x63, 0xe6, 0x63, 0xe6, 0x63, 0x66, 0x62, 0x26, 0x60, 0x06, 0x60, 0x06, 0x7f, 0xfe, 0x3f, 0xfc, 0x00, 0x00 };
const unsigned char Chip[] PROGMEM = { 0x14, 0xa0, 0x3f, 0xf0, 0x7f, 0xf8, 0xe0, 0x1c, 0x6e, 0x18, 0xec, 0x1c, 0x68, 0x18, 0x60, 0x18, 0xe0, 0x1c, 0x60, 0x58, 0xe0, 0x1c, 0x7f, 0xf8, 0x3f, 0xf0, 0x14, 0xa0 };
//const unsigned char HeatPipe[] PROGMEM  = { 0x00, 0x00, 0x09, 0x90, 0x11, 0x88, 0x21, 0x84, 0x11, 0x88, 0x09, 0x90, 0x11, 0x88, 0x21, 0x84, 0x11, 0x88, 0x09, 0x90, 0x11, 0x88, 0x21, 0x84, 0x11, 0x88, 0x09, 0x90, 0x01, 0x80, 0x00, 0x00 };
const unsigned char Lightning[] PROGMEM = { 0x0f, 0xe0, 0x1f, 0xc0, 0x1f, 0xc0, 0x3f, 0x80, 0x3f, 0xf8, 0x7f, 0xf0, 0x7f, 0xe0, 0x07, 0xc0, 0x07, 0x80, 0x0f, 0x00, 0x0e, 0x00, 0x1c, 0x00, 0x18, 0x00, 0x10, 0x00 };
//const unsigned char Thermometer[] PROGMEM = { 0x01, 0x80, 0x02, 0x40, 0x03, 0x40, 0x02, 0x40, 0x03, 0x40, 0x02, 0x40, 0x03, 0x40, 0x02, 0x40, 0x03, 0x40, 0x03, 0xc0, 0x03, 0xc0, 0x03, 0xc0, 0x07, 0xe0, 0x07, 0xe0, 0x07, 0xe0, 0x03, 0xc0 };
const unsigned char Pointer[] PROGMEM = { 0x20, 0x20, 0x70, 0xf8 };
//状态提示
//width:14,height:14 图标库

const unsigned char c1[] PROGMEM = { 0x03, 0x00, 0x07, 0x80, 0x0f, 0xc0, 0x0c, 0xc0, 0x1c, 0xe0, 0x1c, 0xe0, 0x3c, 0xf0, 0x3c, 0xf0, 0x7f, 0xf8, 0x7f, 0xf8, 0xfc, 0xfc, 0xfc, 0xfc, 0xff, 0xfc, 0x7f, 0xf8 };
const unsigned char c2[] PROGMEM = { 0x7f, 0xf8, 0xff, 0xfc, 0xc0, 0x0c, 0xc3, 0x0c, 0xcb, 0x4c, 0xdb, 0x6c, 0xdb, 0x6c, 0xd8, 0x6c, 0xdc, 0xec, 0xcf, 0xcc, 0xc7, 0x8c, 0xc0, 0x0c, 0xff, 0xfc, 0x7f, 0xf8 };
const unsigned char c3[] PROGMEM = { 0x00, 0x00, 0x06, 0x00, 0x0c, 0x00, 0x18, 0xf8, 0x38, 0xf0, 0x30, 0x30, 0x70, 0x60, 0x70, 0x78, 0x78, 0xf8, 0x78, 0x00, 0x3c, 0x02, 0x3f, 0x0c, 0x1f, 0xf8, 0x0f, 0xf0, 0x03, 0xc0, 0x00, 0x00 };
const unsigned char c5[] PROGMEM = { 0x7f, 0xf0, 0xff, 0xe0, 0xc0, 0x08, 0xc0, 0x1c, 0xc0, 0x38, 0xc8, 0x70, 0xdc, 0xe4, 0xcf, 0xcc, 0xc7, 0x8c, 0xc3, 0x0c, 0xc0, 0x0c, 0xc0, 0x0c, 0xff, 0xfc, 0x7f, 0xf8 };
const unsigned char c6[] PROGMEM = { 0x1e, 0x10, 0x33, 0x38, 0x2d, 0x7c, 0x25, 0x38, 0x2d, 0x38, 0x25, 0x38, 0x2d, 0x38, 0x6d, 0x80, 0xde, 0xc0, 0xbf, 0x40, 0xbf, 0x40, 0xde, 0xc0, 0x61, 0x80, 0x3f, 0x00 };
const unsigned char c7[] PROGMEM = { 0x1f, 0xe0, 0x3f, 0xf0, 0x70, 0x38, 0x60, 0x18, 0x60, 0x18, 0x60, 0x18, 0xff, 0xfc, 0xfc, 0xfc, 0xfc, 0xfc, 0xfc, 0xfc, 0xf8, 0x7c, 0xf8, 0x7c, 0xfc, 0xfc, 0x7f, 0xf8 };
const unsigned char c_NO[] PROGMEM  = { 0x80, 0x04, 0x00, 0x00, 0x3f, 0xf0, 0x37, 0xb0, 0x23, 0x10, 0x30, 0x30, 0x38, 0x70, 0x38, 0x70, 0x30, 0x30, 0x23, 0x10, 0x37, 0xb0, 0x3f, 0xf0, 0x00, 0x00, 0x80, 0x04 };
const unsigned char *C_table[] = {c1, c2, c3, Lightning, c5, c6, c7};
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
void loop() {
  //HelpMeSerialer();
  ROTARYCheck();      // check rotary encoder (temp/boost setting, enter setup menu)
  SLEEPCheck();       // check and activate/deactivate sleep modes
  SENSORCheck();      // reads temperature and vibration switch of the iron
  Thermostat();       // heater control
  MainScreen();       // updates the main page on the OLED
  //beep(0);
}




// check rotary encoder; set temperature, toggle boost mode, enter setup menu accordingly
void ROTARYCheck() {
  // set working temperature according to rotary encoder value
  SetTemp = getRotary();

  // check rotary encoder switch
  uint8_t c = digitalRead(BUTTON_PIN);
  if ( !c && c0 ) {
    beep();
    buttonmillis = millis();
    while ( (!digitalRead(BUTTON_PIN)) && ((millis() - buttonmillis) < 500) );
    if ((millis() - buttonmillis) >= 500) SetupScreen();
    else {
      inBoostMode = !inBoostMode;
      if (inBoostMode) boostmillis = millis();
      handleMoved = true;
    }
  }
  c0 = c;

  // check timer when in boost mode
  if (inBoostMode && timeOfBoost) {
    goneSeconds = (millis() - boostmillis) / 1000;
    if (goneSeconds >= timeOfBoost) {
      inBoostMode = false;              // stop boost mode
      beep();                           // beep if boost mode is over
      beepIfWorky = true;               // beep again when working temperature is reached
    }
  }
}


// check and activate/deactivate sleep modes
void SLEEPCheck() {
  if (handleMoved) {                    // if handle was moved
    if (inSleepMode) {                  // in sleep or off mode?
      if ((CurrentTemp + 20) < SetTemp) // if temp is well below setpoint
        analogWrite(CONTROL_PIN, 0);    // then start the heater right now
      beep();                           // beep on wake-up
      beepIfWorky = true;               // beep again when working temperature is reached
    }
    handleMoved = false;                // reset handleMoved flag
    inSleepMode = false;                // reset sleep flag
    inOffMode   = false;                // reset off flag
    sleepmillis = millis();             // reset sleep timer
  }

  // check time passed since the handle was moved
  goneMinutes = (millis() - sleepmillis) / 60000;
  if ( (!inSleepMode) && (time2sleep > 0) && (goneMinutes >= time2sleep) ) {
    inSleepMode = true;
    beep();
  }
  if ( (!inOffMode)   && (time2off   > 0) && (goneMinutes >= time2off  ) ) {
    inOffMode   = true;
    beep();
  }
}


// reads temperature, vibration switch and supply voltages
void SENSORCheck() {
  analogWrite(CONTROL_PIN, 255);              // shut off heater in order to measure temperature
  delayMicroseconds(time2settle);             // wait for voltage to settle

  uint16_t temp = denoiseAnalog(SENSOR_PIN);  // read ADC value for temperature
  uint8_t d = digitalRead(SWITCH_PIN);        // check handle vibration switch
  if (d != d0) {
    handleMoved = true;  // set flag if handle was moved
    d0 = d;
  }
  if (! SensorCounter--) Vin = getVIN();      // get Vin every now and then

  analogWrite(CONTROL_PIN, Output);           // turn on again heater

  RawTemp += (temp - RawTemp) * SMOOTHIE;     // stabilize ADC temperature reading
  calculateTemp();

  // stabilize displayed temperature when around setpoint
  if ((ShowTemp != Setpoint) || (abs(ShowTemp - CurrentTemp) > 5)) ShowTemp = CurrentTemp;

  // set state variable if temperature is in working range; beep if working temperature was just reached
  gap = abs(SetTemp - CurrentTemp);
  if (gap < 5) {
    if (!isWorky && beepIfWorky) beep();
    isWorky = true;
    beepIfWorky = false;
  }
  else isWorky = false;
  // checks if tip is present or currently inserted
  if (ShowTemp > 500) TipIsPresent = false;   // tip removed ?
  if (!TipIsPresent && (ShowTemp < 500)) {    // new tip inserted ?
    analogWrite(CONTROL_PIN, 255);            // shut off heater
    beep();                                   // beep for info
    TipIsPresent = true;                      // tip is present now
    ChangeTipScreen();                        // show tip selection screen
    updateEEPROM();                           // update setting in EEPROM
    handleMoved = true;                       // reset all timers
    RawTemp  = denoiseAnalog(SENSOR_PIN);     // restart temp smooth algorithm
    c0 = LOW;                                 // switch must be released
    setRotary(TEMP_MIN, TEMP_MAX, TEMP_STEP, SetTemp);  // reset rotary encoder
  }
}


// calculates real temperature value according to ADC reading and calibration values
void calculateTemp() {
  if      (RawTemp < 200) CurrentTemp = map (RawTemp,   0, 200,                     21, CalTemp[CurrentTip][0]);
  else if (RawTemp < 280) CurrentTemp = map (RawTemp, 200, 280, CalTemp[CurrentTip][0], CalTemp[CurrentTip][1]);
  else                    CurrentTemp = map (RawTemp, 280, 360, CalTemp[CurrentTip][1], CalTemp[CurrentTip][2]);
}


//调温
void Thermostat() {
  // define Setpoint acoording to current working mode
  if      (inOffMode)   Setpoint = 0;
  else if (inSleepMode) Setpoint = SleepTemp;
  else if (inBoostMode) Setpoint = SetTemp + BoostTemp;
  else                  Setpoint = SetTemp;

  // control the heater (PID or direct)
  gap = abs(Setpoint - CurrentTemp);
  if (PIDenable) {
    Input = CurrentTemp;
    if (gap < 30) ctrl.SetTunings(consKp, consKi, consKd);
    else ctrl.SetTunings(aggKp, aggKi, aggKd);
    ctrl.Compute();
  } else {
    // turn on heater if current temperature is below setpoint
    if ((CurrentTemp + 0.5) < Setpoint) Output = 0; else Output = 255;
  }
  analogWrite(CONTROL_PIN, Output);     // set heater PWM
}


// creates a short beep on the buzzer
void beep() {
  /*
    if (beepEnable) {
    if (BeepCoolTime + SetBeepCoolTime < millis()) {
      if (state) BeepCoolTime = millis();
      analogWrite(BUZZER_PIN, 0);
    }  else analogWrite(BUZZER_PIN, 127);
    } else analogWrite(BUZZER_PIN, 0);
  */
  //体谅一下，没内存了，只能用原始的办法驱动无源蜂鸣器，否则我也不想牺牲宝贵响应资源换内存
  if (beepEnable) {
    for (uint8_t i = 0; i < 255; i++) {
      digitalWrite(BUZZER_PIN, HIGH);
      delayMicroseconds(125);
      digitalWrite(BUZZER_PIN, LOW);
      delayMicroseconds(125);
    }
  }
}

//设置旋转编码器的起始值
// sets start values for rotary encoder
void setRotary(int rmin, int rmax, int rstep, int rvalue) {
  countMin  = rmin << ROTARY_TYPE;
  countMax  = rmax << ROTARY_TYPE;
  countStep = rstep;
  count     = rvalue << ROTARY_TYPE;
}


// reads current rotary encoder value
int getRotary() {
  return (count >> ROTARY_TYPE);
}


// reads user settings from EEPROM; if EEPROM values are invalid, write defaults
void getEEPROM() {
  uint16_t identifier = (EEPROM.read(0) << 8) | EEPROM.read(1);
  if (identifier == EEPROM_IDENT) {
    DefaultTemp = (EEPROM.read(2) << 8) | EEPROM.read(3);
    SleepTemp   = (EEPROM.read(4) << 8) | EEPROM.read(5);
    BoostTemp   =  EEPROM.read(6);
    time2sleep  =  EEPROM.read(7);
    time2off    =  EEPROM.read(8);
    timeOfBoost =  EEPROM.read(9);
    MainScrType =  EEPROM.read(10);
    PIDenable   =  EEPROM.read(11);
    beepEnable  =  EEPROM.read(12);
    CurrentTip  =  EEPROM.read(13);
    NumberOfTips = EEPROM.read(14);
    LANG = EEPROM.read(15);
    FlipState = EEPROM.read(16);
    UnderVoltage = EEPROM.read(17);
    Password = (EEPROM.read(18) << 8) | EEPROM.read(19);
    uint8_t i, j;
    uint16_t counter = 20;
    for (i = 0; i < NumberOfTips; i++) {
      for (j = 0; j < TIPNAMELENGTH; j++) {
        TipName[i][j] = EEPROM.read(counter++);
      }
      for (j = 0; j < 4; j++) {
        CalTemp[i][j]  = EEPROM.read(counter++) << 8;
        CalTemp[i][j] |= EEPROM.read(counter++);
      }
    }
  }
  else {
    EEPROM.update(0, EEPROM_IDENT >> 8); EEPROM.update(1, EEPROM_IDENT & 0xFF);
    updateEEPROM();
  }
}
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

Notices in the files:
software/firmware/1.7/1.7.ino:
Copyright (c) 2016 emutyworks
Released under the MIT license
